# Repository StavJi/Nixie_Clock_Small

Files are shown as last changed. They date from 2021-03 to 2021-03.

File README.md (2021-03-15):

# Nixie_Clock_Small
<p float="left">
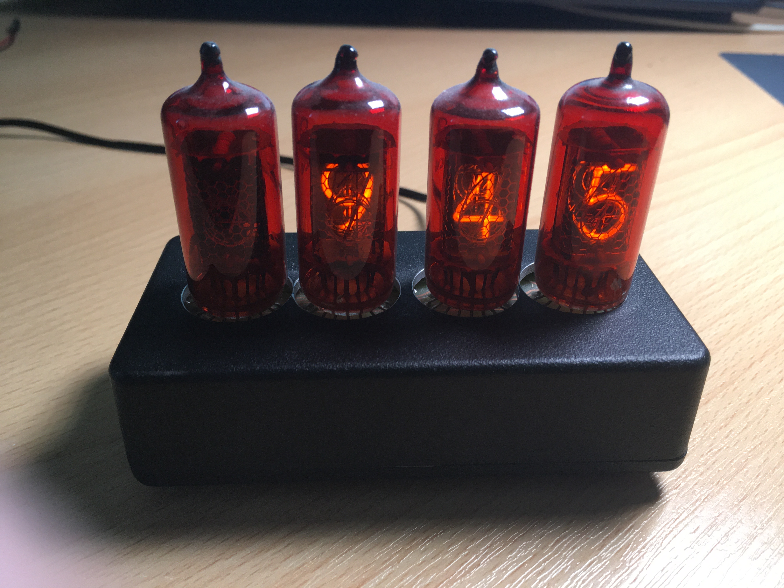
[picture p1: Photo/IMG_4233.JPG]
  
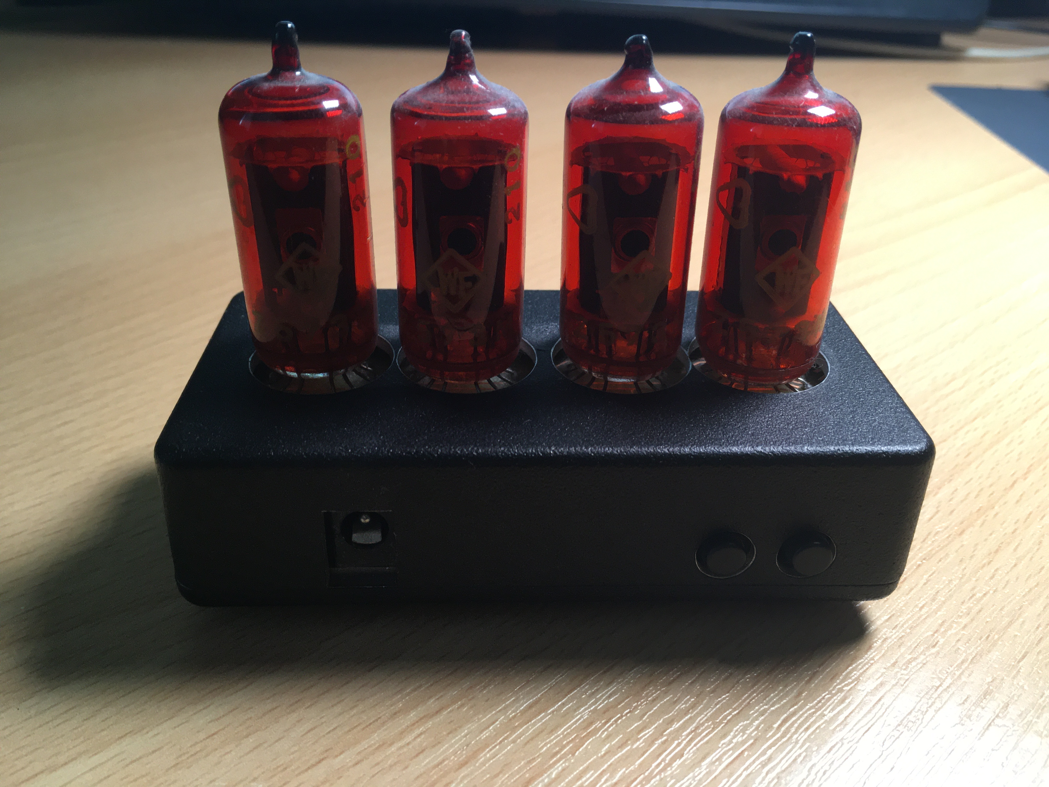
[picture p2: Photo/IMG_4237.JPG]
  
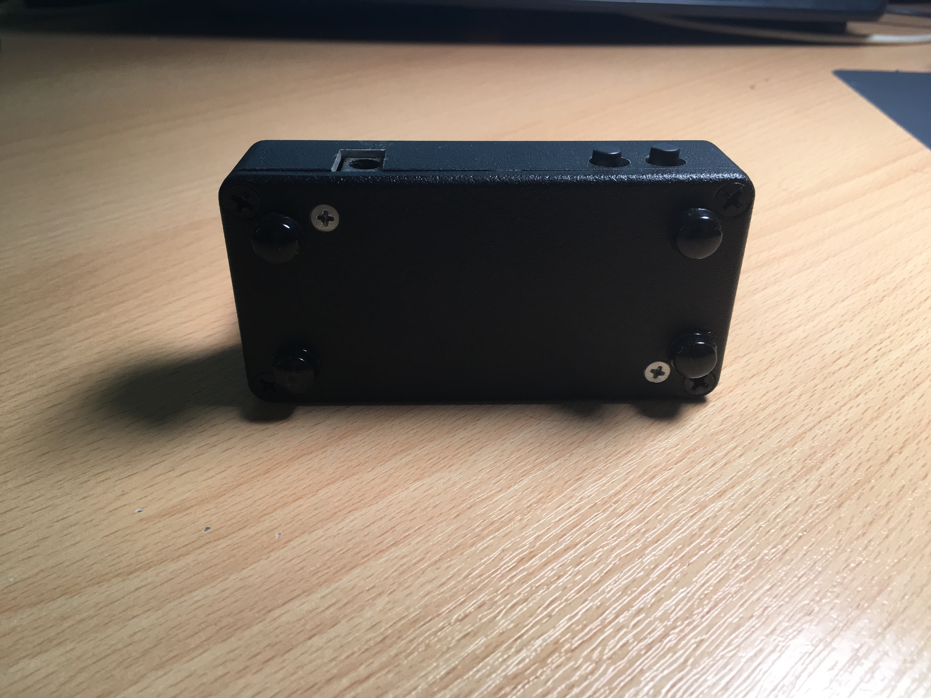
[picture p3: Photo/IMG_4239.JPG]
  
</p>

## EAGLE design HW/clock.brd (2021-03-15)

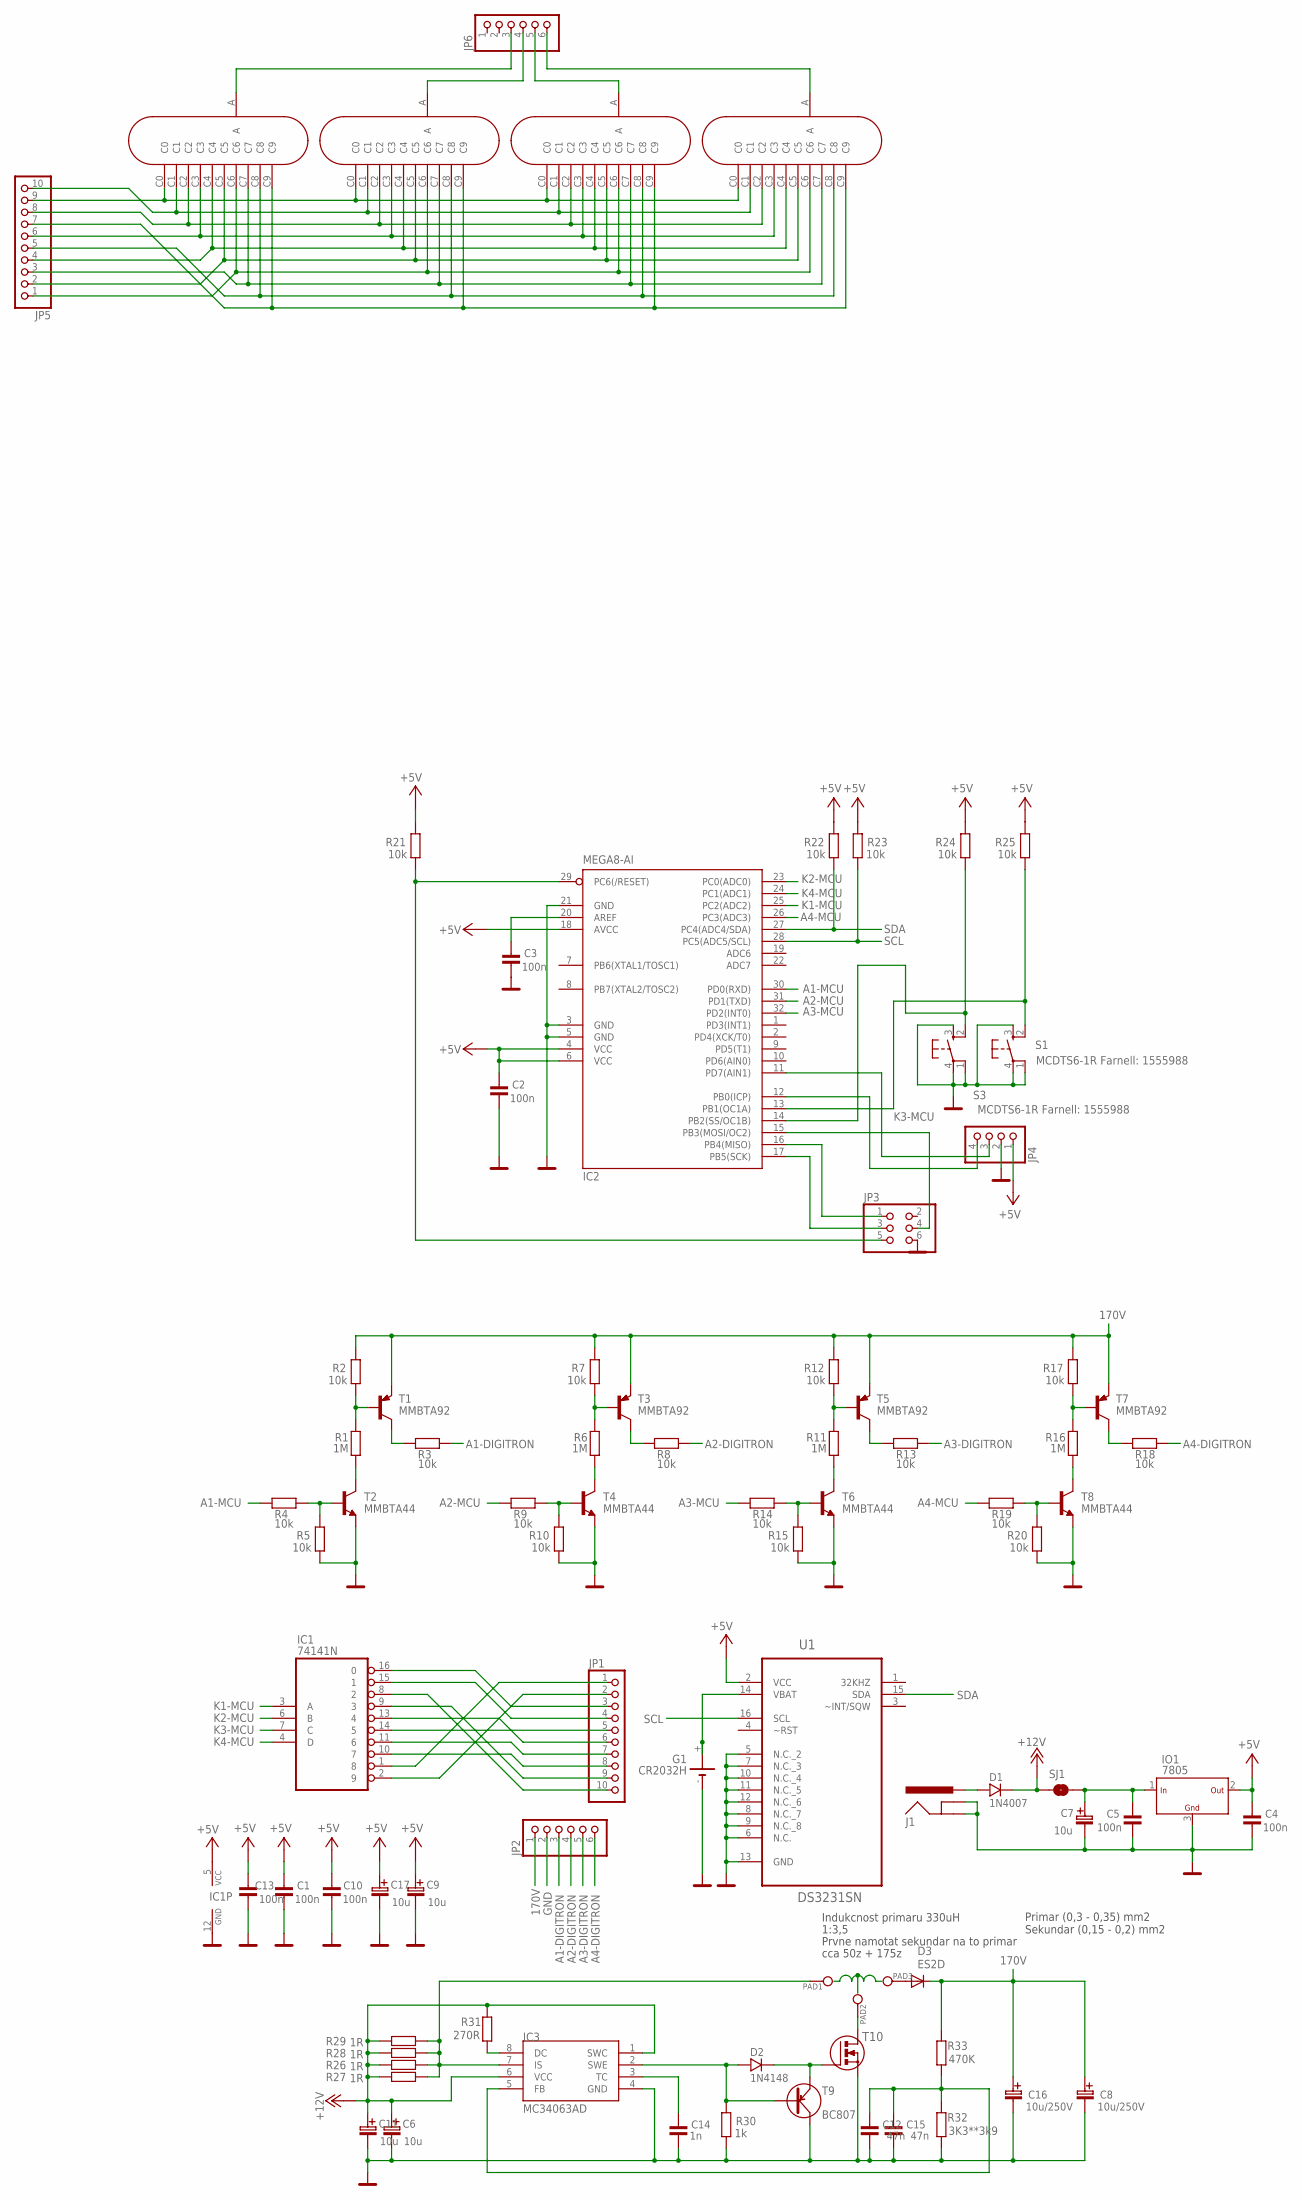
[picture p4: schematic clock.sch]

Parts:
C1, C2, C3, C4, C5, C10, C13: 100n; 0805
C6, C7, C9, C11, C17: 10u; A
C8, C16: 10u/250V; C_EL_5
C12, C15: 47n; 0805
C14: 1n; 0805
D1: 1N4007; SM-1
D2: 1N4148; SOD-80
D3: ES2D; SMB
E1, E2, E3, E4: Z573M
G1: CR2032H
IC1: 74141N; DIL16
IC2: MEGA8-AI; TQFP32-08
IC3: MC34063AD; SOIC8
IO1: 7805; D2PAK
J1: SPARKFUN_POWER_JACKSLT; SPARKFUN_POWER_JACK_SLOT
JP1, JP5: PINHD-1X10; 1X10
JP2, JP6: PINHD-1X6; 1X06
JP3: PINHD-2X3; 2X03
JP4: PINHD-1X4; 1X04
PAD1, PAD2, PAD3: PAD_1,8; PAD_1
R1, R6, R11, R16: 1M; 0805
R2, R4, R5, R7, R9, R10, R12, R14, R15, R17, R19, R20, R21, R22, R23, R24, R25: 10k; 0805
R3, R8, R13, R18: 10k; 1206
R26, R27, R28, R29: 1R; 1206
R30: 1k; 0805
R31: 270R; 0805
R32: 3K3**3k9; 0805
R33: 470K; 0805
S1, S3: MCDTS6-1R Farnell: 1555988; B3F-31XX
SJ1: SOLDERJUMPERNC; SJ-NC
T1, T3, T5, T7: MMBTA92; SOT23-BEC
T2, T4, T6, T8: MMBTA44; SOT23-BEC
T9: BC807; SOT-23
T10: SMD_NFET; D2PAK
U1: DS3231SN; SOIC127P1032X265-16N

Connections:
170V: C8.C+ (C_EL+), C16.C+ (C_EL+), D3.C, JP2.1, R2.2, R7.2, R12.2, R17.2, R33.1, T1.E, T3.E, T5.E, T7.E
+5V: C1.2, C2.2, C4.2, C9.+ (C_EL+), C10.2, C13.2, C17.+ (C_EL+), IC1.5 (VCC), IC2.4 (VCC), IC2.6 (VCC), IC2.18 (AVCC), IO1.2 (OUT), JP4.1, R21.2, R22.2, R23.2, R24.2, R25.2, U1.2 (VCC)
+12V: C6.+ (C_EL+), C11.+ (C_EL+), D1.K, IC3.1 (SWC), IC3.6 (VCC), R26.1, R27.1, R28.1, R29.1, R31.1, SJ1.1
A1-DIGITRON: JP2.3, R3.1
A1-MCU: IC2.30 (PD0(RXD)), R4.2
A2-DIGITRON: JP2.4, R8.1
A2-MCU: IC2.31 (PD1(TXD)), R9.2
A3-DIGITRON: JP2.5, R13.1
A3-MCU: IC2.32 (PD2(INT0)), R14.2
A4-DIGITRON: JP2.6, R18.1
A4-MCU: IC2.26 (PC3(ADC3)), R19.2
GND: C1.1, C2.1, C3.1, C4.1, C5.1, C6.- (C_EL-), C7.- (C_EL-), C8.C- (C_EL-), C9.- (C_EL-), C10.1, C11.- (C_EL-), C12.1, C13.1, C14.1, C15.1, C16.C- (C_EL-), C17.- (C_EL-), G1.-, IC1.12 (GND), IC2.3 (GND), IC2.5 (GND), IC2.21 (GND), IC3.4 (GND), IO1.3 (GND), J1.GND@1 (GNDBREAK), J1.GND@2 (GND), JP2.2, JP3.6, JP4.2, R5.1, R10.1, R15.1, R20.1, R30.1, R32.2, S1.1, S1.3 (S), S1.4, S3.1, S3.3 (S), S3.4, T2.E, T4.E, T6.E, T8.E, T9.3 (C), T10.2 (S), U1.5 (N.C._2), U1.6 (N.C.), U1.7 (N.C._3), U1.8 (N.C._7), U1.9 (N.C._8), U1.10 (N.C._4), U1.11 (N.C._5), U1.12 (N.C._6), U1.13 (GND)
K1-MCU: IC1.3 (A), IC2.25 (PC2(ADC2))
K2-MCU: IC1.6 (B), IC2.23 (PC0(ADC0))
K3-MCU: IC1.7 (C), IC2.15 (PB3(MOSI/OC2)), JP3.4
K4-MCU: IC1.4 (D), IC2.24 (PC1(ADC1))
unnamed: R1.2, R2.1, T1.B
unnamed: R3.2, T1.C
unnamed: R6.2, R7.1, T3.B
unnamed: R1.1, T2.C
unnamed: R4.1, R5.2, T2.B
unnamed: R8.2, T3.C
unnamed: R6.1, T4.C
unnamed: R9.1, R10.2, T4.B
unnamed: R11.2, R12.1, T5.B
unnamed: R13.2, T5.C
unnamed: R11.1, T6.C
unnamed: R14.1, R15.2, T6.B
unnamed: R16.2, R17.1, T7.B
unnamed: R18.2, T7.C
unnamed: R16.1, T8.C
unnamed: R19.1, R20.2, T8.B
unnamed: IC2.29 (PC6(/RESET)), JP3.5, R21.1
unnamed: IC2.14 (PB2(SS/OC1B)), R24.1, S3.2 (S1)
unnamed: C3.2, IC2.20 (AREF)
unnamed: D1.A, J1.PWR
unnamed: IC2.17 (PB5(SCK)), JP3.3
unnamed: G1.+, G1.+@1 (+), U1.14 (VBAT)
unnamed: IC2.13 (PB1(OC1A)), R25.1, S1.2 (S1)
unnamed: IC3.7 (IS), PAD1.1, R26.2, R27.2, R28.2, R29.2
unnamed: C12.2, C15.2, IC3.5 (FB), R32.1, R33.2
unnamed: PAD2.1, T10.3 (D)
unnamed: D3.A, PAD3.1
unnamed: IC1.10 (7), JP1.8
unnamed: IC1.9 (3), JP1.9
unnamed: IC1.11 (6), JP1.7
unnamed: IC1.13 (4), JP1.6
unnamed: IC1.8 (2), JP1.10
unnamed: IC1.14 (5), JP1.5
unnamed: IC1.15 (1), JP1.4
unnamed: IC1.16 (0), JP1.3
unnamed: IC1.1 (8), JP1.1
unnamed: IC1.2 (9), JP1.2
unnamed: C14.2, IC3.3 (TC)
unnamed: D2.A, IC3.2 (SWE), R30.2, T9.1 (B)
unnamed: D2.K, T9.2 (E), T10.1 (G)
unnamed: IC3.8 (DC), R31.2
unnamed: IC2.11 (PD7(AIN1)), JP4.3
unnamed: C5.2, C7.+ (C_EL+), IO1.1 (IN), SJ1.2
unnamed: IC2.12 (PB0(ICP)), JP4.4
unnamed: E2.A, JP6.4
unnamed: E1.C0, E2.C0, E3.C0, E4.C0, JP5.9
unnamed: E1.C1, E2.C1, E3.C1, E4.C1, JP5.10
unnamed: E1.C2, E2.C2, E3.C2, E4.C2, JP5.8
unnamed: E1.C3, E2.C3, E3.C3, E4.C3, JP5.6
unnamed: E1.C4, E2.C4, E3.C4, E4.C4, JP5.4
unnamed: E1.C5, E2.C5, E3.C5, E4.C5, JP5.2
unnamed: E1.C6, E2.C6, E3.C6, E4.C6, JP5.1
unnamed: E1.C7, E2.C7, E3.C7, E4.C7, JP5.3
unnamed: E1.C8, E2.C8, E3.C8, E4.C8, JP5.5
unnamed: E1.C9, E2.C9, E3.C9, E4.C9, JP5.7
unnamed: E3.A, JP6.5
unnamed: E4.A, JP6.6
unnamed: E1.A, JP6.3
SCL: IC2.28 (PC5(ADC5/SCL)), R23.1, U1.16 (SCL)
SDA: IC2.27 (PC4(ADC4/SDA)), R22.1, U1.15 (SDA)
SDASASDA: IC2.16 (PB4(MISO)), JP3.1

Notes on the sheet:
Indukcnost primaru 330uH
1:3,5
Prvne namotat sekundar na to primar
cca 50z + 175z
Primar (0,3 - 0,35) mm2 Sekundar (0,15 - 0,2) mm2

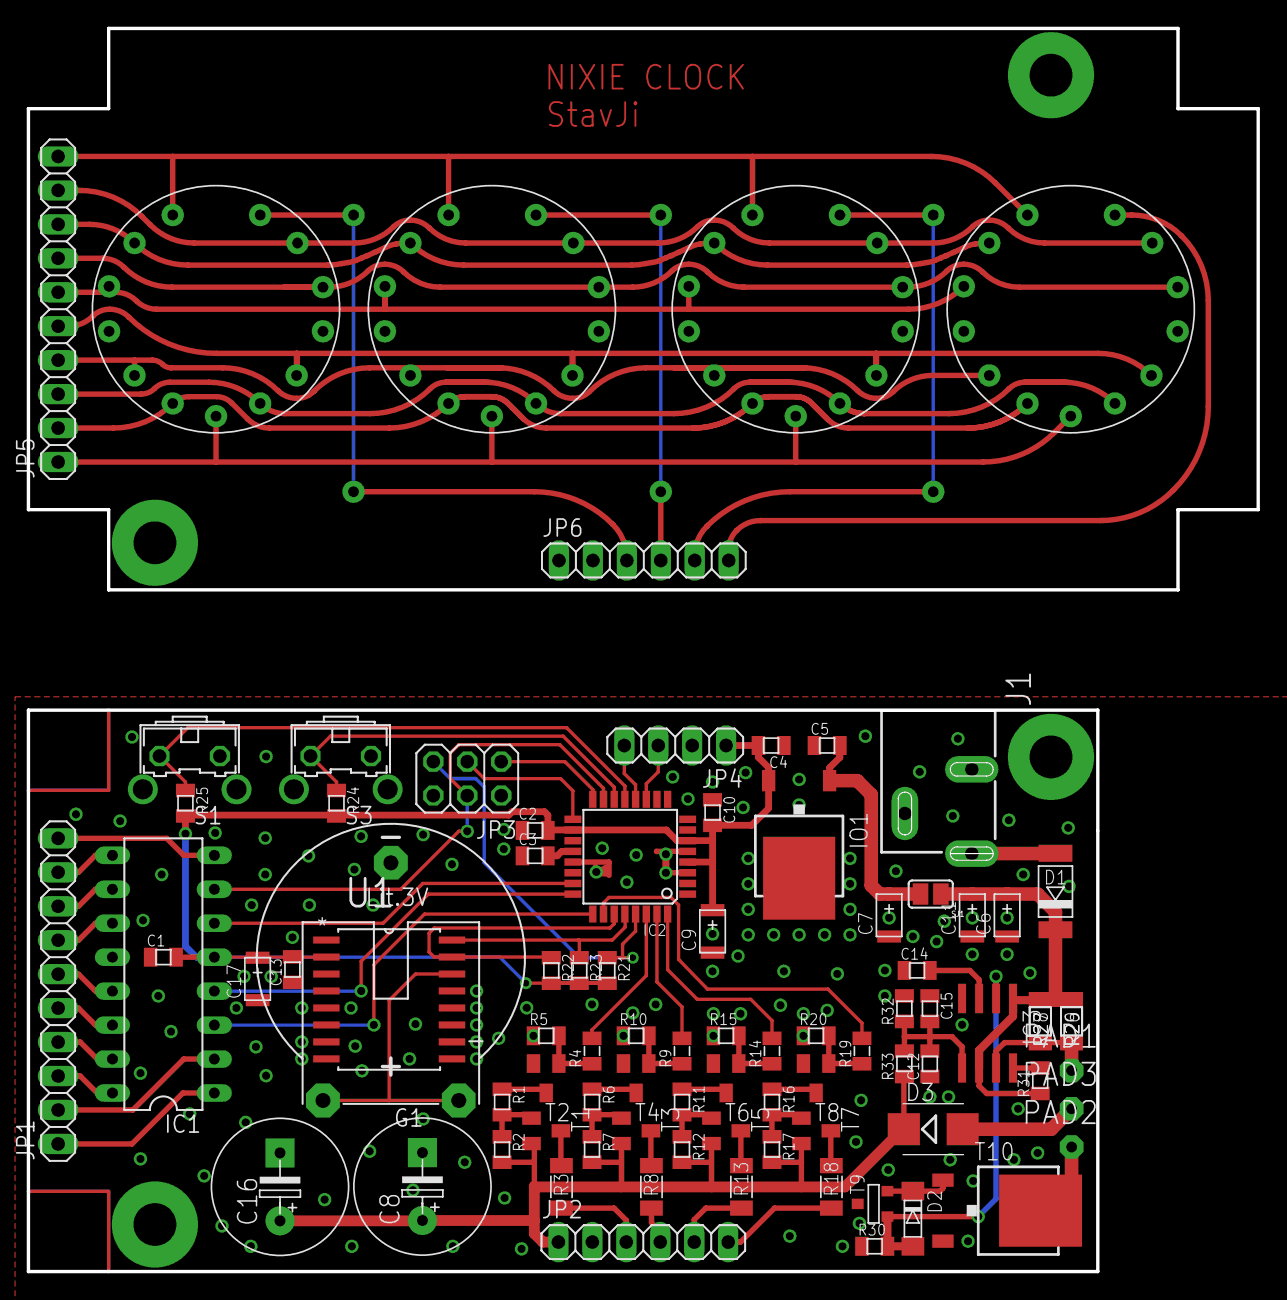
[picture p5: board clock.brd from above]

Board: 2 copper layers, 80.0 x 42.0 mm, 86 parts (0 on the bottom side), 77 nets.

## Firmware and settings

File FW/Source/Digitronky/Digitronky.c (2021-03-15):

#ifdef F_CPU
#undef F_CPU
#endif

#define F_CPU 8000000

#include <avr/io.h>
#include <util/delay.h>
#include <avr/interrupt.h>
#include <stdlib.h>
#include <stdio.h>
#include <math.h>
#include <avr/pgmspace.h>
#include "i2cmaster.h"

#define KATODA_1_PORT		PORTC		// k 74141 - A
#define KATODA_1_DDR		DDRC
#define KATODA_1_NUMBER		2

#define KATODA_2_PORT		PORTC		// k 74141 - B
#define KATODA_2_DDR		DDRC
#define KATODA_2_NUMBER		0

#define KATODA_3_PORT		PORTB		// k 74141 - C
#define KATODA_3_DDR		DDRB
#define KATODA_3_NUMBER		3

#define KATODA_4_PORT		PORTC		// k 74141 - D
#define KATODA_4_DDR		DDRC
#define KATODA_4_NUMBER		1

#define ANODA_1_PORT		PORTD		// k tranzistorum
#define ANODA_1_DDR			DDRD
#define ANODA_1_NUMBER		0

#define ANODA_2_PORT		PORTD		// k tranzistorum
#define ANODA_2_DDR			DDRD
#define ANODA_2_NUMBER		1

#define ANODA_3_PORT		PORTD		// k tranzistorum
#define ANODA_3_DDR			DDRD
#define ANODA_3_NUMBER		2

#define ANODA_4_PORT		PORTC		// k tranzistorum
#define ANODA_4_DDR			DDRC
#define ANODA_4_NUMBER		3

#define TLACITKO_1_PORT		PORTB		// tlacitko 1
#define TLACITKO_1_DDR		DDRB
#define TLACITKO_1_PIN		PINB
#define TLACITKO_1_NUMBER	1

#define TLACITKO_2_PORT		PORTB		// tlacitko 2
#define TLACITKO_2_DDR		DDRB
#define TLACITKO_2_PIN		PINB
#define TLACITKO_2_NUMBER	2

// ******* NEMENIT ******* //
#define TLACITKO_1_ZMACKNUTO	( (TLACITKO_1_PIN & (1 << TLACITKO_1_NUMBER) ) == 0)					// zjisteni zda doslo ke stisku tlacitka
#define TLACITKO_2_ZMACKNUTO	( (TLACITKO_2_PIN & (1 << TLACITKO_2_NUMBER) ) == 0)

#define TLACITKO_MAX_TIME	15000

#define TLACITKO_MENU		1			// prirazeni funkce tlacitkum
#define TLACITKO_OK			2

#define DIGITS_OFF			KATODA_1_PORT |= (1 << KATODA_1_NUMBER); KATODA_2_PORT |= (1 << KATODA_2_NUMBER); KATODA_3_PORT |= (1 << KATODA_3_NUMBER); KATODA_4_PORT |= (1 << KATODA_4_NUMBER);		

#define ANODE_OFF			ANODA_1_PORT &= ~(1 << ANODA_1_NUMBER);	ANODA_2_PORT &= ~(1 << ANODA_2_NUMBER); ANODA_3_PORT &= ~(1 << ANODA_3_NUMBER);	ANODA_4_PORT &= ~(1 << ANODA_4_NUMBER);
#define ANODE_1_ON			ANODA_1_PORT |= (1 << ANODA_1_NUMBER)
#define ANODE_2_ON			ANODA_2_PORT |= (1 << ANODA_2_NUMBER)
#define ANODE_3_ON			ANODA_3_PORT |= (1 << ANODA_3_NUMBER)
#define ANODE_4_ON			ANODA_4_PORT |= (1 << ANODA_4_NUMBER)

// Adresy RTC

#define DS3231SN			0xD0//0x68	// adresa obvodu
#define RTC_SEC				0x00		// adresa sekund
#define RTC_MIN				0x01		// adresa minut
#define RTC_HOD				0x02		// adresa hodin
#define RTC_DAY				0x04		// den
#define RTC_WEEK_DAY		0x03		// den v tydnu
#define RTC_MONTH			0x05		// mesic + stoleti				
#define RTC_YEAR			0x06		// rok			



// ******* NEMENIT ******* //

// Prevodni tabulka, ktera odpovida rozlozeni na DPS
unsigned char cislice[11]=
{
	//ABCD
	0b00000101,				// 5 - 0
	0b00000001,				// 8 - 1
	0b00001101,				// 7 - 2
	0b00001000,				// 1 - 3
	0b00000100,				// 2 - 4
	0b00000110,				// 6 - 5
	0b00000010,				// 4 - 6
	0b00000000,				// 0 - 7
	0b00001100,				// 3 - 8
	0b00001001,				// 9 - 9
	0b00001111,				// zhasnuto
};

volatile unsigned char disp[6] = {10,10,10,10,10,10};	// globalni promenna pro zobrazovaci rutinu, zapsanim 10 se cislice zhasne
volatile uint8_t pos;									// index prave zobrazovane pozice
volatile uint8_t blikej = 0;							// promenna urcujici zda se ma blikat a kterou cislici aktivni spodni polovina bajtu
volatile uint8_t blikej_cnt = 0;						// pocitadlo pro blikani
volatile uint8_t temp = 0, i2cdata = 0;					// pomocne promenne
volatile uint16_t time_tl_1 = 0;						// promenna urcujici delku zmacknuteho tlacitka
volatile uint16_t time_tl_2 = 0;						// promenna urcujici delku zmacknuteho tlacitka
volatile uint16_t timer = 0;							// casovani pri necinnosti
volatile uint8_t tlacitko_1 = 0;						// co ma dane tlacitko vykonavat
volatile uint8_t tlacitko_2 = 0;						// co ma dane tlacitko vykonavat
volatile uint8_t stop = 0;								// pomocna promenna, ktera zastavi hodiny

volatile uint8_t hodiny = 0, minuty = 0, sekundy = 0;

signed char UART_test[30];								// promenna na test programu po UARTu

void init(void);
void zobraz_cislo(uint8_t cislo);
void read(unsigned char reg);
void write(unsigned char reg);
void read_time(char *dest);

int main(void)
{
    uint8_t previousHour = 0, actualHours = 0;
	
	//SW_UART_Init();
	i2c_init();
	init();
	
	i2cdata = 128;
	
	read(RTC_SEC);
	
	_delay_ms(10);
	
	if(i2cdata > 127)				// hodiny nenastaveny, nastavit nulovy vychozi cas
	{
		i2cdata = 0;
		write(RTC_HOD);
		i2cdata = 0;
		write(RTC_MIN);
		i2cdata = 0;
		write(RTC_SEC);
	}
	
	// Load and save actual hours
	read_time((char*)&disp[0]);
	actualHours = disp[1];
	
	_delay_ms(10);
	
	sei();	// povol globalni preruseni
	
	for(;;)
	{
		
		if(stop)
		{
			blikej = 0b00000011;										// blikej hodiny
			
			while(stop)
			{
				while(TLACITKO_1_ZMACKNUTO || TLACITKO_2_ZMACKNUTO);	// nepokracuj dokud je zmacknute nektere tlacitko
		
				_delay_ms(200);
				tlacitko_1 = 0;
				tlacitko_2 = 0;
				timer = 40000;
				
				while( (tlacitko_2 != TLACITKO_OK) && (timer != 0) )
				{
					if (tlacitko_1 == TLACITKO_OK)
					{
						timer = 40000;
						
						disp[1]++;
												
						if( (disp[1] > 3) && (disp[0] > 1) )
						{
							disp[1] = 0;
							disp[0]++;
						}
						
						if( (disp[1] > 9) && (disp[0] < 2) )
						{
							disp[1] = 0;
							disp[0]++;
						}
						
						if(disp[0] > 2) disp[0] = 0;
						
						while(TLACITKO_1_ZMACKNUTO);
						tlacitko_1 = 0;
					}
				}
				
				if(timer != 0)
				{
					blikej = 0b00001100;					// blikej minuty
					timer = 40000;
				
					while (TLACITKO_2_ZMACKNUTO);			// dokud se nepusti tlacitko nic nedelej
				
					_delay_ms(200);
					tlacitko_1 = 0;
					tlacitko_2 = 0;
								
					while( (tlacitko_2 != TLACITKO_OK) && (timer != 0) )
					{
						if (tlacitko_1 == TLACITKO_OK)
						{
							timer = 40000;
						
							disp[3]++;
						
							if (disp[3] > 9)
							{
								disp[3] = 0;
								disp[2]++;
							}
						
							if(disp[2] > 5) disp[2] = 0;
						
							while(TLACITKO_1_ZMACKNUTO);
							tlacitko_1 = 0;
						}
					}
				
					if (tlacitko_2 == TLACITKO_OK)
					{
						blikej = 0;							// stop blikani
						disp[4] = 0;						// vynulovat sekundy
						disp[5] = 0;
					
						i2cdata = ((disp[0]<<4)+disp[1]);	// slozit BCD hodnotu
						write(RTC_HOD);
						i2cdata = ((disp[2]<<4)+disp[3]);	// slozit BCD hodnotu
						write(RTC_MIN);
						i2cdata = 0;
						write(RTC_SEC);
						
						// Save actual hours
						previousHour = disp[1];
						actualHours = disp[1];
						
						_delay_ms(20);		
					
						blikej = 0b00001111;		
								
						while(TLACITKO_2_ZMACKNUTO);
					
						while(1)
						{
							_delay_ms(3000);
							break;
						}
					}
				}
					blikej = 0;
					stop = 0;						// odchod z menu
				
			}
		}
		else
		{											// normalni stav zobrazuji se hodiny
			//cli();
			previousHour = disp[1];
			read_time((char*)&disp[0]);
			actualHours = disp[1];
			
			// Each hour iterate over each digit to prevent cathode poisoning
			if (previousHour != actualHours)
			{
				for (uint8_t i = 0; i < 10; i++ )
				{
					disp[0] = i;
					disp[1] = i;
					disp[2] = i;
					disp[3] = i;
					_delay_ms(500);
				}
			}
			
		//	sei();
			
/*			SW_UART_Write_Byte(disp[0]+48);
			SW_UART_Write_Byte(disp[1]+48);
			SW_UART_Write_Data(":",1);
			SW_UART_Write_Byte(disp[2]+48);
			SW_UART_Write_Byte(disp[3]+48);
			SW_UART_Write_Data(":",1);
			SW_UART_Write_Byte(disp[4]+48);
			SW_UART_Write_Byte(disp[5]+48);
			SW_UART_Write_Data("\n",1);*/	
							
			_delay_ms(50);		
		}
	}
	
	return 0;										// nikdy sem nedojne ale nejsem prase
}

void init (void)
{
	// vystupy - katody
	KATODA_1_DDR |= (1 << KATODA_1_NUMBER);
	KATODA_2_DDR |= (1 << KATODA_2_NUMBER);
	KATODA_3_DDR |= (1 << KATODA_3_NUMBER);
	KATODA_4_DDR |= (1 << KATODA_4_NUMBER);
	
	// vystupy anody
	ANODA_1_DDR |= (1 << ANODA_1_NUMBER);
	ANODA_2_DDR |= (1 << ANODA_2_NUMBER);
	ANODA_3_DDR |= (1 << ANODA_3_NUMBER);
	ANODA_4_DDR |= (1 << ANODA_4_NUMBER);
	
	// vstupy pro tlacitka
	TLACITKO_1_DDR &= ~(1 << TLACITKO_1_NUMBER);
	TLACITKO_2_DDR &= ~(1 << TLACITKO_2_NUMBER);
	
	// timer 0 - multiplex - cca 330Hz
	TCCR0B |= (1 << CS02);							// preddelicka 256	
	TIMSK0 |= (1 << TOIE0);							// povoleni casovace 2
	TCNT0 = 162;									// 330Hz
	//TCNT0 = 248;									// 3900Hz
	// plny chod 122Hz
	//TCNT0 = 100;									// 200Hz
	
	// timer 2 - 3900 Hz 
	TCCR2B |= (1 << CS21);							// preddelicka 8
	TIMSK2 |= (1 << TOIE2);							// poveleni casovace 2
	
	OSCCAL = 0xAE;									// kalibracni konstanta oscilatoru, nevim jestli funguje
}

void zobraz_cislo(uint8_t cislo)
{
	if (cislice[cislo] & (1 << KATODA_1_NUMBER))	// rozhodnuti zda se bude zapisovat 0 nebo 1
	{
		KATODA_1_PORT |= (1 << KATODA_1_NUMBER);	// zapis log 1
	}
	else
	{
		KATODA_1_PORT &= ~(1 << KATODA_1_NUMBER);	// zapis log 0
	}
	
	if (cislice[cislo] & (1 << KATODA_2_NUMBER))	// rozhodnuti zda se bude zapisovat 0 nebo 1
	{
		KATODA_2_PORT |= (1 << KATODA_2_NUMBER);	// zapis log 1
	}
	else
	{
		KATODA_2_PORT &= ~(1 << KATODA_2_NUMBER);	// zapis log 0
	}
		
	if (cislice[cislo] & (1 << KATODA_3_NUMBER))	// rozhodnuti zda se bude zapisovat 0 nebo 1
	{
		KATODA_3_PORT |= (1 << KATODA_3_NUMBER);	// zapis log 1
	}
	else
	{
		KATODA_3_PORT &= ~(1 << KATODA_3_NUMBER);	// zapis log 0
	}
			
	if (cislice[cislo] & (1 << KATODA_4_NUMBER))	// rozhodnuti zda se bude zapisovat 0 nebo 1
	{
		KATODA_4_PORT |= (1 << KATODA_4_NUMBER);	// zapis log 1
	}
	else
	{
		KATODA_4_PORT &= ~(1 << KATODA_4_NUMBER);	// zapis log 0
	}
}

void read(unsigned char reg)
{
	i2c_start_wait(DS3231SN+I2C_WRITE);					// zapis do DS3231
	i2c_write(reg);									// adresa bunky
	i2c_rep_start(DS3231SN+I2C_READ);				// cteni z DS3231
	i2cdata = i2c_readNak();						// ulozit prectenou hodnotu do globalni promenne
	i2c_stop();		               					// stop
}

void write(unsigned char reg)
{
	i2c_start_wait(DS3231SN+I2C_WRITE);
	i2c_write(reg);	        						// 	vyber adresy( hodiny minuty atd)
	i2c_write(i2cdata);								// 	zapise BCD na vybranou adresu
	i2c_stop(); 									//	stop
}

void read_time(char *dest)							// funkce pro vycteni casu z RTC do zvoleneho pole
{
	read(RTC_SEC);
	dest[5]=(i2cdata & 0x0F);
	dest[4]=((i2cdata >>4)& 0b00000111);
	read(RTC_MIN);
	dest[3]=(i2cdata & 0x0F);
	dest[2]=((i2cdata >>4)& 0b00000111);
	read(RTC_HOD);
	dest[1]=(i2cdata & 0x0F);
	dest[0]=((i2cdata >>4)& 0b00000011);
	blikej = 0;
}

ISR(TIMER0_OVF_vect)								// multiplex
{
	TCNT0 = 162;									// 330Hz
	//TCNT0 = 248;									// 3900Hz
	// plny chod 122Hz
	//TCNT0 = 100;									// 200Hz
	
	ANODE_OFF;
	DIGITS_OFF;				// zhasnout vsechno

	temp = (1 << pos);
	
	blikej_cnt++;
	
	if(blikej_cnt > 340) blikej_cnt = 0;			// perioda blikani cca 1 sekunda

	if(blikej & temp)								// blikat zvolenou cislici
	{
		if(blikej_cnt > 50)							// sviti dele nez je zhasnuto
		{
			zobraz_cislo(disp[pos]);
		}
	}
	else
	{												// blikani cislici je vypnuto
		zobraz_cislo(disp[pos]);					// zobraz trvale
	}
	
	switch (pos)			// vybrat anodu, skenovani tlacitek
	{
		case 0:					// sileny if osetruje situaci, aby nesvitila nula (napr. 09:42), ale aby svitila v situaci 00:15
		if( ( (disp[0] < 10) && (disp[0] > 0) ) || ( (disp[0] < 10) && (disp[0] == 0) && (disp[1] == 0)) )			// pokud neni nic zobrazeno, nepripoji se ani anoda,
		{							// aby neprosvitala sousedni cislice
			ANODE_1_ON;
		}
			
		break;
		case 1:
		if (disp[1] < 10)
		{
			ANODE_2_ON;
		}
		break;
		case 2:
		if (disp[2] < 10)
		{
			ANODE_3_ON;
		}
		break;
		case 3:
		if (disp[3] < 10)
		{
			ANODE_4_ON;
		}
		break;
	}// end switch
	
	
	pos++;							// prepnout dalsi cislici
	if (pos > 3) pos = 0;
}			

ISR(TIMER2_OVF_vect)								// tlacitka
{
	if (TLACITKO_1_ZMACKNUTO)
	{
		time_tl_1++;
	}
	else
	{
		time_tl_1 = 0;
	}
	
	if (TLACITKO_2_ZMACKNUTO)
	{
		time_tl_2++;
	}
	else
	{
		time_tl_2 = 0;
	}
	
	if(stop == 1)
	{
		if(timer != 0)
		{
			timer--;
		}
	}
	
	
	if (stop == 0)
	{
		if(time_tl_1 > 10000) stop = 1;				// menu
		
		if(time_tl_2 > 10000) stop = 1;				// menu
				
		if(time_tl_1 > TLACITKO_MAX_TIME) time_tl_1 = 0;
			
		if(time_tl_2 > TLACITKO_MAX_TIME) time_tl_2 = 0;
	}
	
	if (stop == 1)
	{
		if(time_tl_1 > 40)
		{
			time_tl_1 = 0;
			tlacitko_1 = TLACITKO_OK;
		}
		
		if(time_tl_2 > 40)
		{
			time_tl_2 = 0;
			tlacitko_2 = TLACITKO_OK;
		}
	}
}

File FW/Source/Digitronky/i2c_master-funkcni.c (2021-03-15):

#ifdef F_CPU
#undef F_CPU
#endif

#define F_CPU 8000000

#include "i2c_master.h"

/****************************************************
    inicializacna funkcia i2c zbernice - master
****************************************************/

void i2c_init(void)
{
    TWSR = 0;                         //bez delicky
    TWBR = ((F_CPU/SCL_CLOCK)-16)/2;  //hodnota TWBR musi byt viac ako 10 t.j. FCPU > 3.6 MHz
}

/****************************************************
    start podmienka
    - smer prenosu
    - na zbernicu zapise adresu zariadenia
    - vrati 0 - po bezchybnom priebehu
    - vrati 1 - neuspesny start
    - vrati 2 - adresa nepotvrdena ACk bitom
****************************************************/

unsigned char i2c_start(unsigned char address, unsigned char dir)
{
	// posle start podmienku
	TWCR = (1<<TWINT) | (1<<TWSTA) | (1<<TWEN);

	// caka na jej prijatie
	while(!(TWCR & (1<<TWINT)));

	// kontrola TWSR
	if (((TWSR & 0xF8) != TW_START) && ((TWSR & 0xF8) != TW_REP_START)) return 1;

	// odosle adresu zariadenia s urcenim smeru prenosu dat
	TWDR = address | dir;
	TWCR = (1<<TWINT) | (1<<TWEN);

	// caka na dokoncenie presnosu
	while(!(TWCR & (1<<TWINT)));

	// kontrola TWSR
	if (((TWSR & 0xF8) != TW_MT_SLA_ACK) && ((TWSR & 0xF8) != TW_MR_SLA_ACK)) return 2;

	return 0;
}

/****************************************************
    opakovana start podmienka
****************************************************/

unsigned char i2c_rep_start(unsigned char address, unsigned char dir)
{
	return (i2c_start(address,dir));
}

/****************************************************
    stop podmienka
    - vrati 0 - po bezchybnom priebehu
    - vrati 1 - po neuspesnom stop
****************************************************/

unsigned char i2c_stop(void)
{
    	//odosle stop podmienku
	TWCR = (1<<TWINT)|(1<<TWEN)|(1<<TWSTO);

	//pocka na jej dokoncenie
	while(!(TWCR & (1<<TWSTO)));

	if ((TWSR & 0xF8) != TW_SR_STOP) return 1;

	return 0;
}

/****************************************************
    vysielanie byte-u na zbernicu
    - vrati 0 - po uspesnom vysielani - potvrdene s ACK
    - vrati 1 - data nepotvrdene ACK bitom
****************************************************/

unsigned char i2c_write(unsigned char data)
{
	//odosle data na predtym adresovane zariadenie
	TWDR = data;
	TWCR = (1<<TWINT)|(1<<TWEN);

	//caka na dokoncenie odosielania
	while(!(TWCR & (1<<TWINT)));

	//skontroluje stav TWSR
	if((TWSR & 0xF8) != TW_MT_DATA_ACK) return 1; 
	return 0; 
}

/****************************************************
    prijem byte-u zo zbernice - nie je posledny
    - vrati prijaty bajt a nasleduje dalsi bajt
****************************************************/

unsigned char i2c_read_Ack(void)
{
	TWCR = (1<<TWINT) | (1<<TWEN) | (1<<TWEA);
	while(!(TWCR & (1<<TWINT)));

        return TWDR;
}

/****************************************************
    prijem byte-u zo zbernice - posledny bajt
    - vrati prijaty bajt a nasleduje stop bit
****************************************************/

unsigned char i2c_read_nAck(void)
{
	TWCR = (1<<TWINT) | (1<<TWEN);
	while(!(TWCR & (1<<TWINT)));

        return TWDR;
}

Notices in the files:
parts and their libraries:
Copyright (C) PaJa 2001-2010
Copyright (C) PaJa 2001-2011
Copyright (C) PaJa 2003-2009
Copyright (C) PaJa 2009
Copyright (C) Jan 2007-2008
